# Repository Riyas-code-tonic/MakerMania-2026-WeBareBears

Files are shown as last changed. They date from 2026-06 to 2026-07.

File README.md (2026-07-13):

# MakerMania-2026-WeBareBears 
> Location: MBF Tinkerers' Lab 007
>
> Team Size: 3–5 Students
>
> Goal: Identify a real-world problem and develop an innovative, patentable, and implementable solution.

---

# 1. Team Identity

## 1.1 Team Name : We Bare Bears
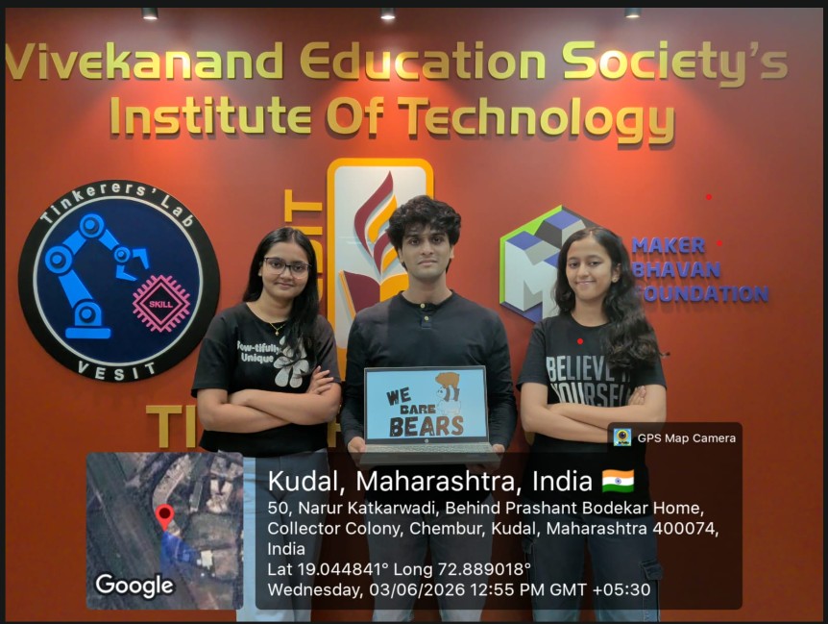
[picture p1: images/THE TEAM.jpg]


---

## 1.2 Team Members

| Name | Role | YEAR | BRANCH |
| ---- | ---- | ---- | ---- |
| Riya Pailwan | DSP & Bluetooth pairing | SE |  ETCS |
| Ankita Karmakar |  Design & Prototype | FE |  EXTC |
| Arsalan Lunje | DSP & Bluetooth pairing |  SE |  AURO |

---

# 2. Problem Discovery

## 2.1 Observation Area

Where did you conduct your observations?

Observations were conducted while travelling as a pillion passenger on a motorcycle in real urban road conditions, directly experiencing the communication difficulties caused by wind noise, engine noise, and surrounding traffic

---

## 2.2 AEIOU Observation Sheet

### Activities

What are users doing?

Riders  turn their heads, rely on shoulder taps, wait for traffic stops, or even pull over to communicate, creating inconvenience and potential safety risks.

### Environment

What conditions affect them?

Communication between riders and pillions is heavily affected by wind, engine, and traffic noise, especially at high speeds where normal conversation becomes difficult. Helmet design, rider-pillion positioning, road vibrations, weather, and high temperatures further reduce speech clarity and make effective communication challenging.

### Interactions
Who or what are they interacting with?

The rider’s attention is focused on operating the motorcycle, making communication difficult and secondary. The pillion usually communicates by shouting or tapping the rider’s shoulder, but communication is one-sided and often hindered by surrounding noise. Existing solutions like phone earbuds do not effectively address rider–pillion communication.

### Objects

What tools or products are used?

At present, most rider–pillion pairs rely on shouting or hand gestures to communicate, as there are no widely used dedicated communication tools. While premium Bluetooth intercom systems exist, they are expensive and require both users to wear compatible helmet-mounted devices. Mobile phones and earbuds are mainly used for music or navigation and do not effectively solve rider–pillion communication.

### Users

Who are the primary users?

The primary users are motorcycle riders who frequently travel with a pillion, including daily commuters, couples, families, students, and touring enthusiasts. These riders often face communication difficulties due to road and wind noise, making a simple and affordable communication solution highly valuable. The rider is the primary purchaser, while the pillion directly benefits from improved communication. By offering an easy-to-use system that does not require both users to wear specialized helmets, the solution targets a broad market and provides a practical, cost-effective alternative to expensive premium intercom systems.

---

## 2.3 Observation Log

| Observation | Evidence | Pain Point |
| --- | --- | --- |
| Rider and pillion struggle to communicate while riding. | I personally faced this issue as a pillion rider when I could not clearly hear what the rider was saying during the journey. | Miscommunication and inability to have clear conversations during the ride. |
| Riders often use unsafe or inconvenient methods to communicate. | Riders turn their heads, shout, or rely on shoulder taps and hand gestures. | Reduced riding safety and distraction from the road. |
| Existing communication systems are expensive or impractical. | Premium Bluetooth intercoms require both users to wear compatible helmet devices and can be costly. | Most everyday riders do not have access to an affordable communication solution. |

---

# 3. User Research

## 3.1 Interview Summary

Number of users interviewed: ___3___

## 3.2 Key Quotes

1. "The wind and engine noise make it difficult to hear what the other person is saying while riding."

2. "I often have to repeat myself several times before my message is understood."

3. "I sometimes need to turn back while riding just to communicate with the pillion passenger."

---

## 3.3 User Persona

## *Persona 1*

**Name:** Ashish Waghmare

**Age:** 20

**Occupation:** Student

**Goals:**
Stay connected with the pillion passenger without interrupting the journey.

**Frustrations:**
Having to repeatedly turn back to communicate with the pillion passenger.

**Needs:**
A hands-free communication solution for rider–pillion interaction.

## *Persona 2*

**Name:** Aarush Srivastava

**Age:** 20

**Occupation:** Student 

**Goals:**
To ensure safe riding while also communicating efficientlty

**Frustrations:**
When trying to communicate something specific, riders often have to shout
and repeat themselves multiple times before the pillion can understand the message 

**Needs:** 
Clear and reliable voice transmission while commuting.

## *Persona 3*

**Name:** Ekansh Bansode

**Age:** 19

**Occupation:** Student

**Goals:**
Stay focused on the road while riding.

**Frustrations:**
Pillion passengers needing to lean forward to be heard.

**Needs:**
Comfortable inside the helmet and proper comunication without interference

---

# 4. Problem Framing

## Problem Statement

A motorcycle rider and pillion passenger need a way to communicate clearly during travel because road, wind, and engine noise make verbal communication difficult and unsafe.

---

## How Might We Questions

1. How might we enable clear communication between a motorcycle rider and pillion without requiring both to wear specialized helmets?

2. How might we improve communication without requiring riders to shout or repeat themselves?

3. How might we allow riders to communicate hands-free without distracting them from riding?

---

## Opportunity Ranking

| Criteria | Score (/10) |
| --- | --- |
| Severity | 8 |
| Frequency | 8 |
| Feasibility | 7 |
| Novelty | 7 |
| Market Potential | 8 |
| **Total** | **38 / 50** |

---

# 5. Solution Ideation

| Idea | Advantages | Challenges |
| --- | --- | --- |
| **Helmet Communication System** – Enables clear rider-to-pillion communication wirelessly. | Improves communication, affordable, enhances riding convenience. | Wind noise, Bluetooth integration, and battery management. |
| **Underground Pipe Leak Detection** – Detects hidden water leaks using acoustic sensors. | Early leak detection, saves water, reduces repair costs. | Noise filtering and underground deployment complexity. |
| **Smart Lost Device Finder** – Locates misplaced remotes, earbuds, and other wireless devices. | Saves time, easy to use, reduces frustration. | Limited range and dependence on tracking hardware. |

---

## Selected Concept : Helmet Communication System

Why was this concept chosen?

We chose the **Helmet Communication System** because it addresses a problem we have personally experienced. As a pillion rider, I often found it difficult to hear what the rider was saying due to wind, traffic, and engine noise, making communication frustrating and ineffective. We also observed that many other riders and pillions face the same issue but usually accept it as a normal part of riding rather than seeking a solution. Although communication systems already exist, they typically require **both the rider and the pillion to wear compatible helmet-mounted devices**, making them expensive and impractical for everyday use. Our concept aims to provide a simpler, more affordable solution that enables clear communication without requiring both users to use specialized helmets.

---

# 6. System Design

## High-Level Description

The proposed system is a low-cost wireless rider–pillion communication solution designed for motorcycles. The rider's or pillion passenger's voice is captured using an INMP441 MEMS microphone, which converts sound into digital audio data and transmits it to the ESP32 through the I²S protocol.

The ESP32 performs audio processing functions such as noise filtering, gain control, voice enhancement, and audio formatting to improve speech clarity in noisy riding environments. The processed audio is then converted into analog audio output using the ESP32's built-in DAC and transmitted through ESP's built in bluetooth module.

The ESP wirelessly streams the audio via Bluetooth to a paired Bluetooth earbud or earpiece, allowing clear communication between the rider and pillion passenger.

The system is powered by a 3.7V Li-Po battery charged through a TP4056 charging module. A 7Semi 5V to 3.3V 1A LDO regulator provides a stable 3.3V supply to the ESP32 and INMP441 microphone, while the RS2597 Bluetooth module is powered directly from the Li-Po battery.

---

## Block Diagram

Insert diagram here.
```text

                        ┌───────────────────┐    ┌───────────────────┐    ┌───────────────────┐       ┌───────────────────┐    ┌───────────────────┐
                        │   Voice Input     │───►│  Voice Capture    │───►│ Audio Processing  │─────► │ Audio Received    │───►│   Clear Audio     │
                        │                   │    │                   │    │ & Noise Reduction │       │         by        │    │      Heard        │
                        │ Rider / Pillion   │    │ INMP441 MEMS Mic  │    │      ESP32        │       │ Bluetooth Earbud  │    │     by User       │
                        │      Speaks       │    │                   │    │                   │       │   / Earpiece      │    │                   │
                        └───────────────────┘    └─────────▲─────────┘    └─────────▲─────────┘       └───────────────────┘    └───────────────────┘
                                                                                    │                                               
                                                                                    │                                              
                                                                           3.3 V Stable Power                    
                                                                                    │                           
                                                                                    │                             
                        ┌───────────────────┐    ┌───────────────────┐    ┌───────────────────┐                 
                        │  TP4056 Module    │───►│   Li-Po Battery   │───►│ 7Semi 5V to 3.3V  │                 
                        │ Charging &        │    │ 3.0V - 4.2V       │    │      1A LDO       │                 
                        │ Protection        │    │ (Nom. 3.7V)       │    │   3.3V Output     │                  
                        └───────────────────┘    └───────────────────┘    └───────────────────┘                
                                                                                                                          
```
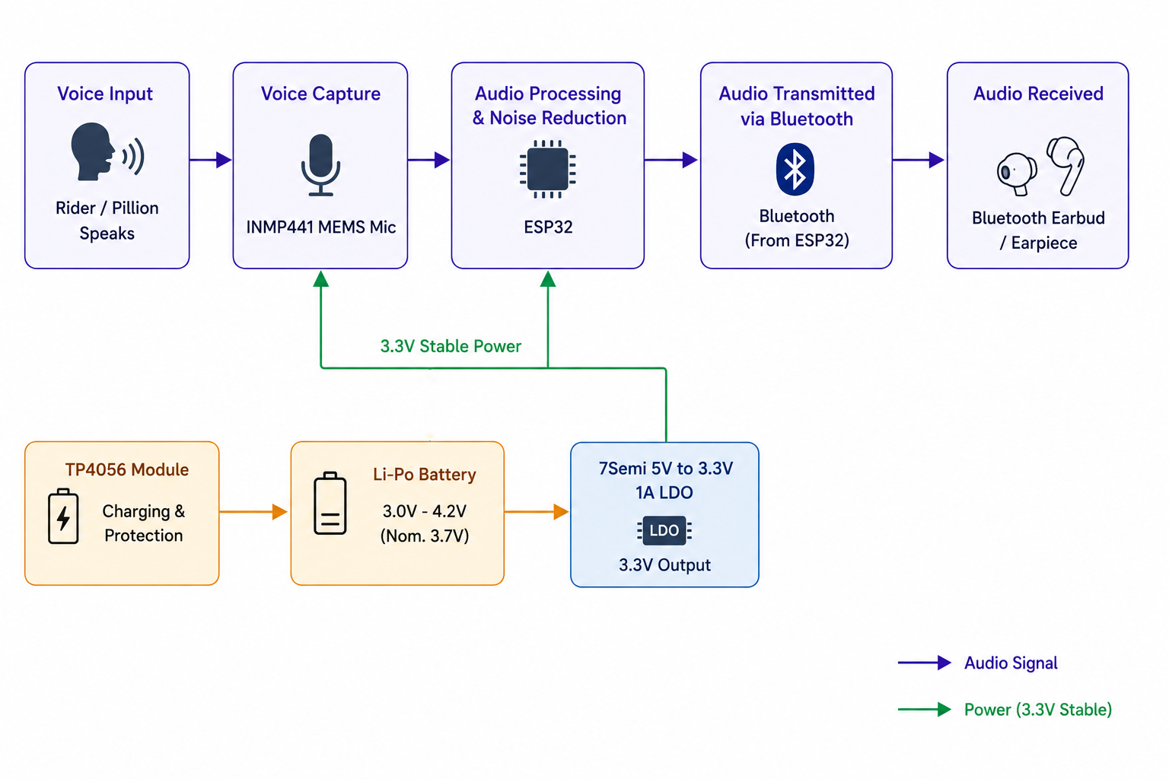
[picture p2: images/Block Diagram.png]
Block Diagram

## System Architecture

                    ┌─────────────┐
                    │   TP4056    │
                    │  Charging   │
                    │  Module     │
                    └──────┬──────┘
                           │
                           ▼
                    ┌─────────────┐
                    │ Li-Po       │
                    │ Battery     │
                    │ 3.7V        │
                    └───┬─────────┘
                        │     
                        │     
                        │     
                        │ 
                        │    ┌─────────────────┐
                        │    │ Bluetooth Earbud│
                        │    └────────▲────────┘
                        │             │
                        │             │
                        ▼             │─ DAC─► Analog Audio 
                 ┌─────────────┐      │─ Noise Filtering
                 │ 7Semi 5V to │      │─ Gain Control
                 │ 3.3V 1A LDO │      │─ Voice Enhancement
                 └──────┬──────┘      │─ Audio Formatting
                        │             │
                        ▼             │
                 ┌─────────────┐  I²S │
                 │   ESP32     │──────│
                 └──────▲──────┘
                        │ 
                        │
                 ┌──────│──────┐
                 │  INMP441    │
                 │ MEMS Mic    │
                 └─────────────┘
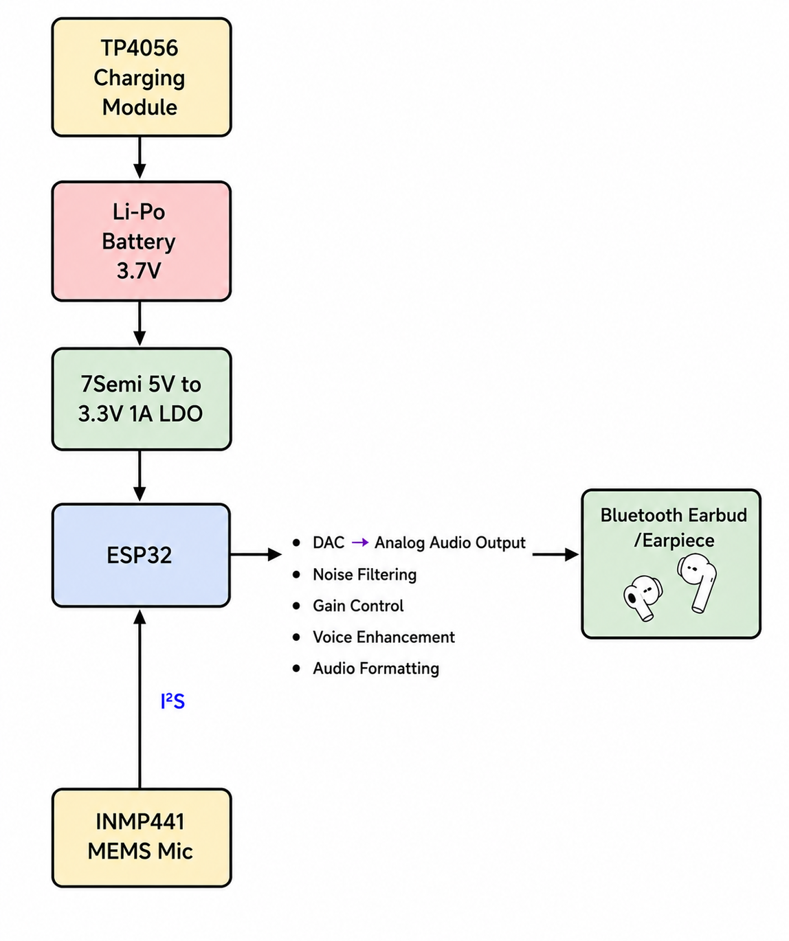
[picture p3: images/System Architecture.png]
System Architecture
               
## Inputs

List sensors, user inputs, data sources.
|INPUT|SOURCE|
|---|---|
|Rider Voice|INMP441 MEMS Microphone|
|Power Supply|3.7V Li-Po Battery|
---

## Outputs

List displays, actuators, software outputs.
|OUTPUT|DEVICE|
|---|---|
|Processed Audio Communication|Bluetooth Earbud|
---

# 7. Technical Planning

## Electronics

|Sr.No. | Component | Purpose | Links|
|--| ---- | --- | --- |
|1.| INMP441 MEMS Microphone |Captures the rider's or pillion's voice and converts it into digital audio data using the I2S interface. |https://robu.in/product/inmp441-mems-high-precision-omnidirectional-microphone-module-i2s/|
|2.| ESP32 Dev Kit V1 |Acts as the main controller, processes audio data, performs noise filtering, and manages wireless communication. |https://www.amazon.in/Generic-ESP32-Dev-Kit-V1/dp/B0H26254W7|
|3.| TP4056 Charging Module |Charges and protects the lithium-ion battery from overcharging and over-discharging. |https://robu.in/product/tp4056-1a-li-ion-lithium-battery-charging-module-with-current-protection-type-c/|
|4.| 3.7V Li-Po Battery |Provides portable power to the entire communication system. |https://www.amazon.in/Bhajanlal-Greenery-Rechargeable-Lithium-Batteries/dp/B0CYQ6H8FW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|
|5.| Bluetooth Earbud |Receives and plays the transmitted audio to the user. ||
|6.| 7Semi 5V to 3.3V 1A LDO Low Dropout Regulator |Provides a stable 3.3V supply to the ESP32, INMP441, and other low-voltage components. |https://evelta.com/7semi-5v-to-3-3v-1a-ldo-low-dropout-regulator-breakout-with-enable/|

Component List : [📄 Component List](docs/Component%20List.docx)
---

## Software

| Tool | Purpose |
| ---- | --- |
|  Arduino IDE | processesing audio data, dsp, performs noise filtering, and manages wireless communication. |

---

## Mechanical / CAD
[Prototype 2 - RideConnect STL](cad/Prototype2%20-%20RideConnect.stl)
Describe fabricated components.

---

# 8. Prototype Development

## Version 1

Description: The first prototype focused on validating the communication concept. Individual components such as the ESP32, MEMS microphone, Bluetooth module, and power supply were tested independently to ensure proper functionality.

Lessons Learned:
- Verified the functionality of individual hardware components before system integration.
- Identified the importance of testing each module independently to simplify debugging.
- Gained an understanding of power requirements, hardware compatibility, and communication interfaces.

---

## Version 2

Description: The immediate prototype involved integrating all the selected hardware components into a single compact embedded system to validate the concept. An ESP32 microcontroller was interfaced with the INMP441 MEMS microphone using the I²S protocol to capture digital audio, while a Bluetooth audio module was used to transmit the processed voice wirelessly to a Bluetooth earbud.
Initial firmware was developed to perform basic audio acquisition, signal processing, and wireless transmission. Testing of the prototype helped identify issues such as wind noise interference, audio latency, power stability, and Bluetooth connectivity. Based on these observations, the system was further refined by optimizing the audio processing pipeline, improving power management, and enhancing the overall reliability of the communication system.

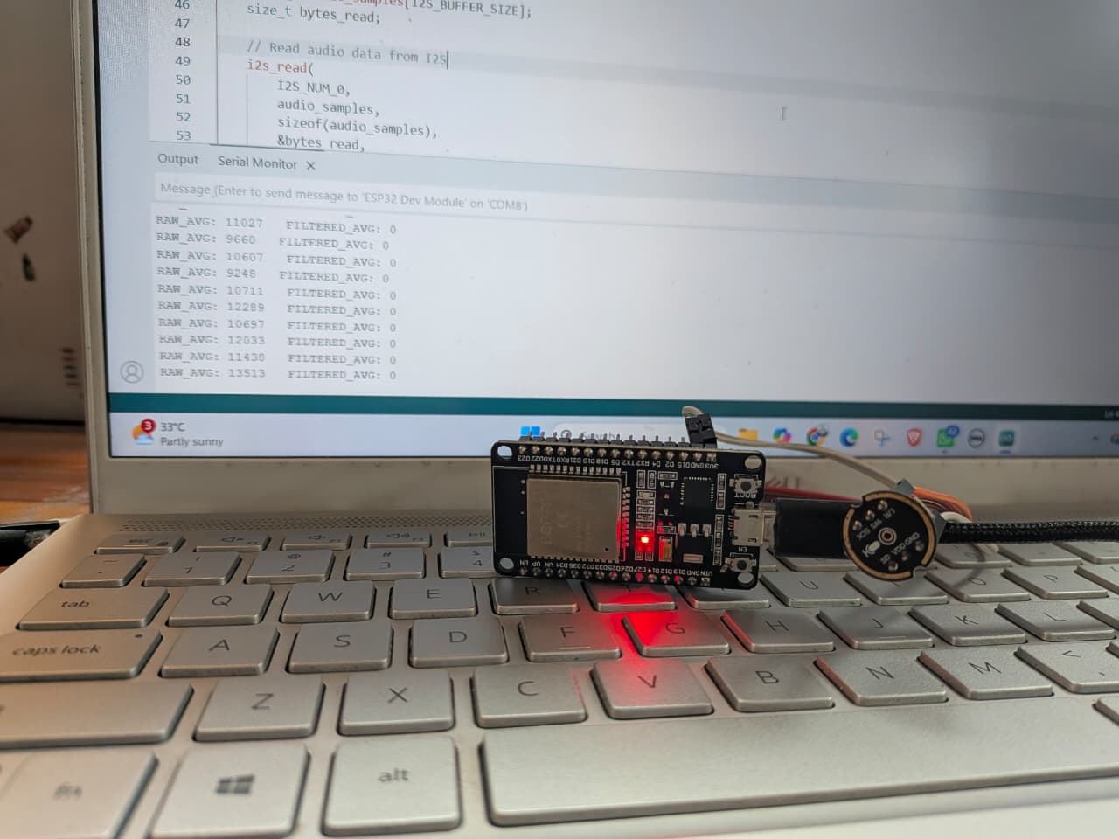
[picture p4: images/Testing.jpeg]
Testing


Lessons Learned:
- Integrating all hardware components introduced challenges such as speech clipping, audio latency, Bluetooth pairing issues, and wind noise interference.
- DSP algorithms required extensive tuning to achieve a balance between noise reduction, amplification, and speech clarity.
- Stable Bluetooth connectivity and efficient power management were essential for reliable real-time communication.
- Testing in different environments helped identify practical limitations and guided further optimization of the system.

---

## Final Prototype

Description: The final prototype consists of an ESP32-based communication unit powered by a rechargeable Li-Po battery. An INMP441 MEMS microphone captures the rider's or pillion's voice, while the ESP32 processes the audio using noise reduction and gain control algorithms. The processed audio is transmitted wirelessly to a Bluetooth earbud, enabling clear communication without requiring specialized helmet-mounted intercoms. The design is lightweight, portable, rechargeable, and cost-effective, making it suitable for daily commuters as well as long-distance riders.

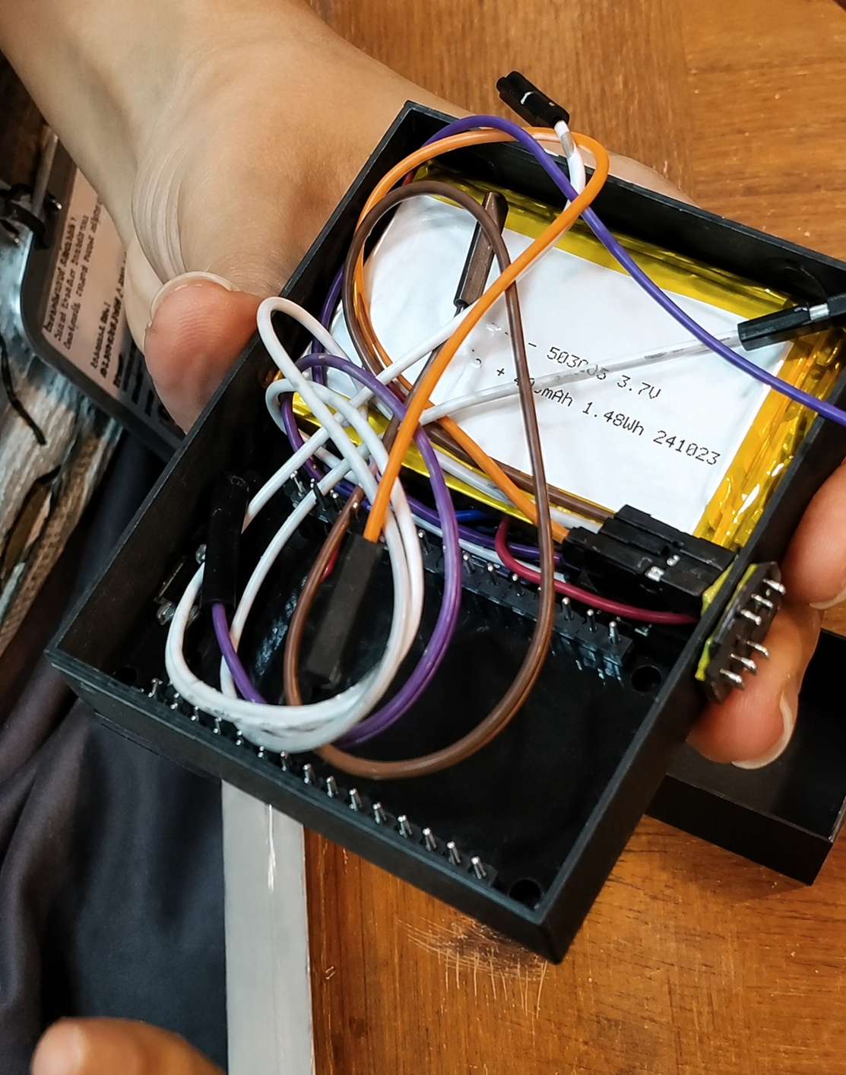
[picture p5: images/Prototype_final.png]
Final Prototype

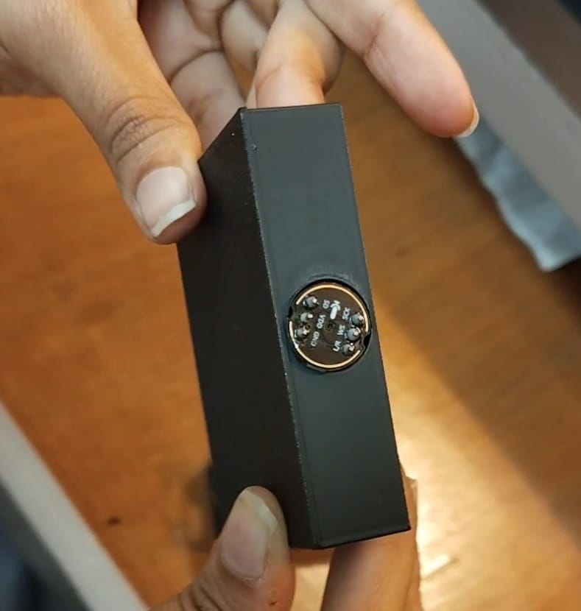
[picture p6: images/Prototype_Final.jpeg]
Final Prototype

---

# 9. Testing & Validation

## Testing Plan

| Test | Success Criteria |
|---|---|
| Audio Capture | MEMS microphone accurately captures speech with minimal distortion. |
| Audio Transmission | Speech is transmitted wirelessly to the Bluetooth earbuds without interruptions. |
| DSP Performance | Noise reduction and gain control improve speech clarity while preserving voice quality. |
| Latency Test | End-to-end audio delay remains low enough for comfortable real-time communication. |

---

## User Feedback

| User | Feedback | Action Taken |
| ---- | --- | --- |
| | | |

---

# 10. Innovation Assessment

## Existing Solutions

List competing products.

---

## What Makes This Different?

---

## Innovation Score

| Parameter | Score |
| --- | ----- |
| Novelty | |
| Technical Depth | |
| Feasibility | |
| Impact | |
| Scalability | |

---

# 11. Intellectual Property

## Prior Art Search

Patents / Products Found:

---

## Novel Features

1.

2.

3.

---

## Provisional Patent Draft

### Title

### Abstract

### Problem

### Solution

### Claims

---

# 12. Business & Deployment

## Target Users

---

## Estimated Cost

---

## Market Opportunity

---

## Sustainability Considerations

---

# 13. Final Demonstration

## Prototype Images

Insert photos.

---

## Demonstration Video Link

---

## GitHub Repository

---

## Presentation Link

---

# 14. Reflection

## What Worked Well?

---

## What Failed?

---

## Key Learnings

---

## Next Steps

* Patent Filing
* Startup Exploration
* Product Development
* Research Publication
* Competition Submission

---

# 15. Final Deliverables Checklist

* Problem Discovery Complete
* User Interviews Complete
* Persona Created
* Problem Statement Finalized
* System Design Complete
* Prototype Demonstrated
* Testing Completed
* Patent Draft Prepared
* Presentation Submitted
* GitHub Repository Updated

---

# MAKERMANIA FINAL PITCH

Each team will present:

1. Problem
2. User Research
3. Insights
4. Solution
5. Prototype Demo
6. Innovation & Patentability
7. Future Roadmap

Presentation Time: 5 Minutes

Q&A: 3 Minutes

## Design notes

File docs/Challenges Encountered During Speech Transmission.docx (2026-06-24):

Challenges Encountered During Speech Transmission

While developing the speech communication system using a MEMS microphone, ESP32, and Bluetooth earbuds, the following issues were identified:

1. Initial Speech Clipping The first word or a few initial syllables of a spoken sentence are occasionally omitted during transmission.
2. Inter-Sentence Audio Loss When transitioning from one sentence to the next, portions of speech may be dropped, resulting in incomplete audio transmission.
3. End-of-Sentence Clipping The last few letters or syllables of a sentence are sometimes not transmitted successfully.
4. Bluetooth Pairing Security The earbuds should only connect to the intended communication module and must be protected from unauthorized pairing attempts while in pairing mode.
5. Connection Stability Once connected, the earbuds should maintain the Bluetooth connection and should only disconnect when placed back into their charging case.
6. Wind Noise Interference Wind noise significantly affects microphone performance and reduces speech intelligibility in outdoor environments.
7. Speech Latency Noticeable delay exists between speech capture and audio playback, impacting real-time communication.

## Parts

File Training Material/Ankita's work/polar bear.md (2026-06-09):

## 2 June 2026 
-> 3D modelling in Fusion360, learning modelling of a bottle

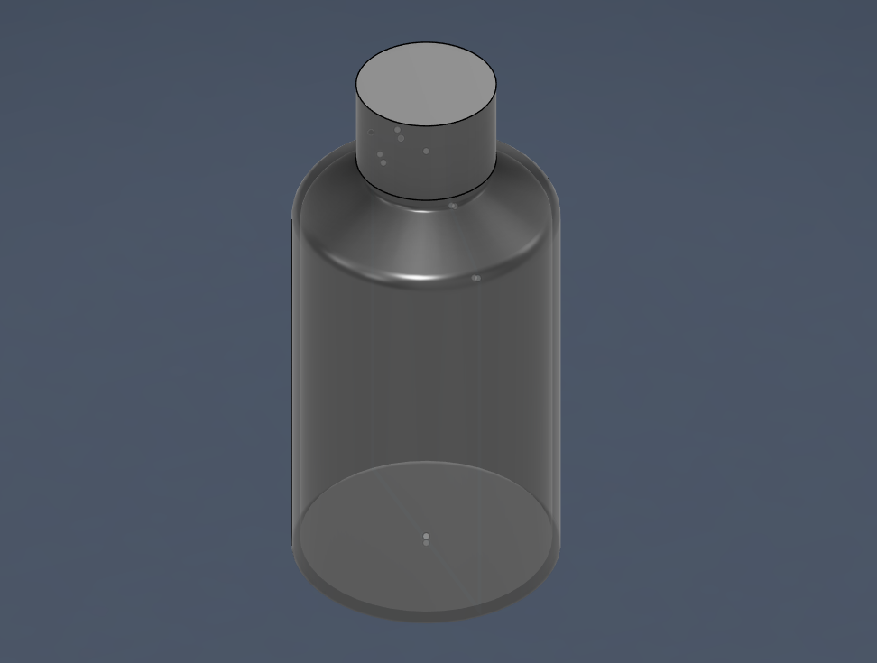
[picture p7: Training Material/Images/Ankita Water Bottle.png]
Ankita Water Bottle


-> Google Meet with an Alumnus, Prithvi Shetty. Spoke about his project 'TARA' and the critical roadmap to building and selling a product.

## 3 June 2026 
-> 3D models of stuffing box and keychain

-> Laser Cutting, learned to laser cut designs as keychains

-> Brainstorming useless product ideas

## 4 June 2026 
-> Laser cut MBFTL IDs

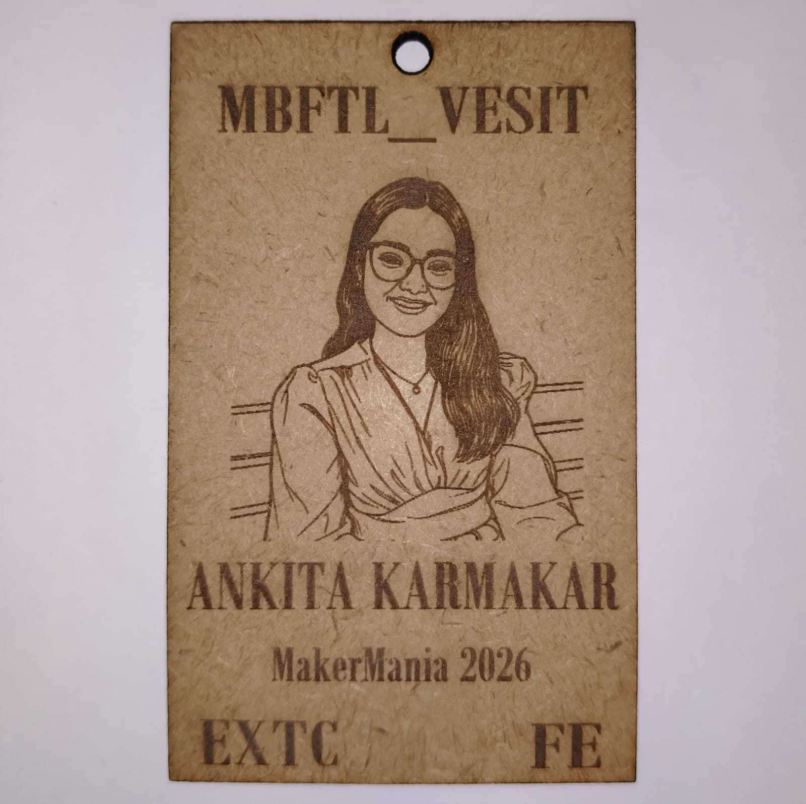
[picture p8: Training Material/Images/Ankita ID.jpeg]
Ankita ID


-> 3D modelling final selected useless product

-> Learned 3D printing

-> 3D printed our 'USELESS' product

## 5 June 2026 ->
Recorded the pitch video for our *USELESS* product.

## 6 June 2026

- Edited the pitch video for our *USELESS* product.
- Uploaded the final video.
### Video
[Watch the Final Video](https://youtu.be/IZlCxVAjYFc)

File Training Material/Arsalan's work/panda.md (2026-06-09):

## 2 June 2026 
-> 3D modelling in Fusion360, learning modelling of a bottle

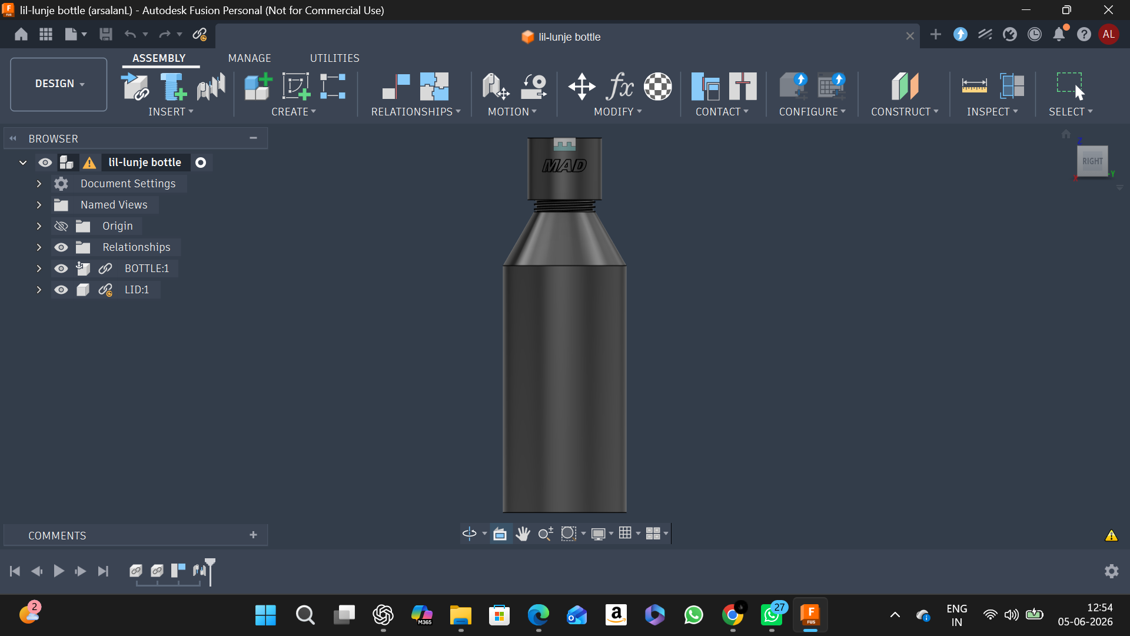
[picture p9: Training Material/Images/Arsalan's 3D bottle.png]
Arsalan's 3D Bottle


-> Google Meet with an Alumnus, Prithvi Shetty. Spoke about his project 'TARA' and the critical roadmap to building and selling a product.

## 3 June 2026 
-> 3D models of stuffing box and keychain

-> Laser Cutting, learned to laser cut designs as keychains

-> Brainstorming useless product ideas

## 4 June 2026 
-> Took a leave

## 5 June 2026 
-> Laser cut MBFTL IDs

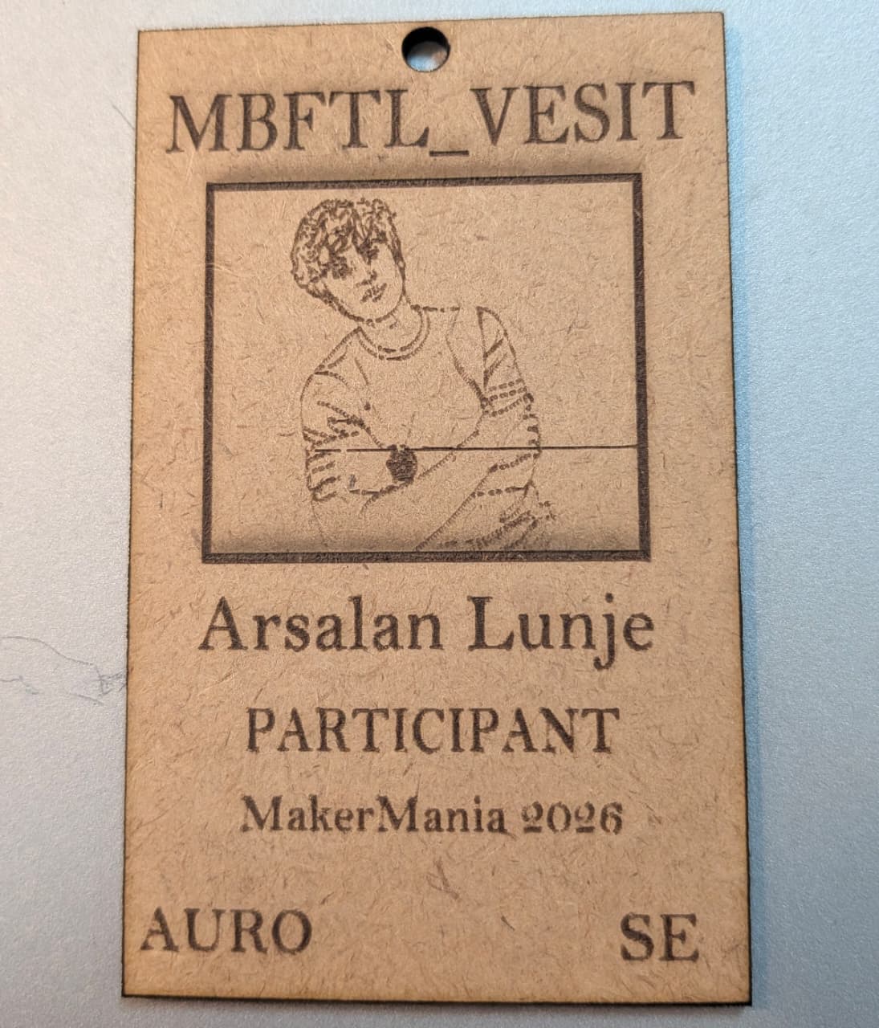
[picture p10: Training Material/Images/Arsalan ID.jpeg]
Arsalan ID


## 6 June 2026

- Edited the pitch video for our *USELESS* product.
- Uploaded the final video.
### Video
[Watch the Final Video](https://youtu.be/IZlCxVAjYFc)

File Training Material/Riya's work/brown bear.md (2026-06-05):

# Riya's MakerMania Work Log

## 2 June 2026

- Learned 3D modelling in Fusion 360 by creating a bottle model.

### Photo
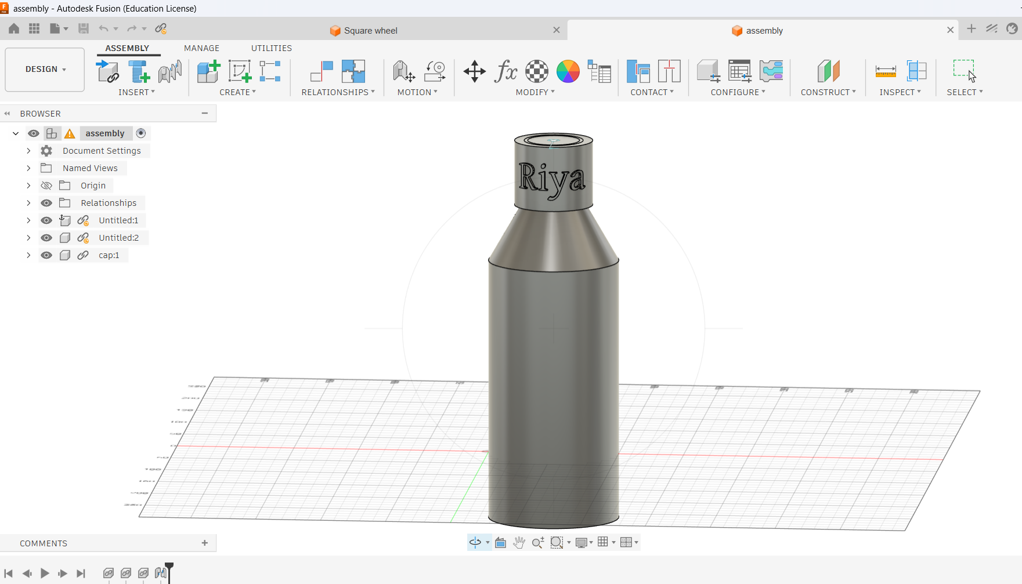
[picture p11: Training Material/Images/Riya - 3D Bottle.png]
Bottle Model


- Attended a Google Meet with alumnus **Prithvi Shetty**.
  - Discussed his project **TARA**.
  - Learned about the roadmap for building and selling a product.

---

## 3 June 2026

- Created 3D models of:
  - Stuffing Box
  - Keychain

- Learned laser cutting and created keychain designs.
- Brainstormed ideas for a useless product.

---

## 4 June 2026

- Laser-cut MBFTL ID cards.

### Photo
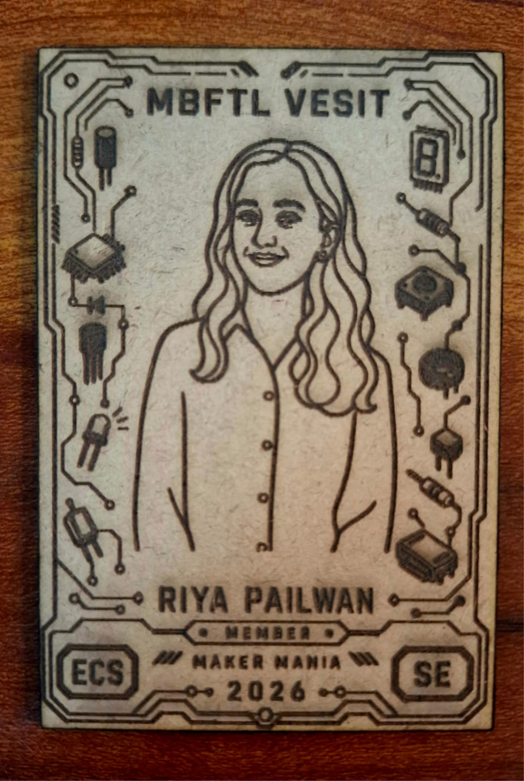
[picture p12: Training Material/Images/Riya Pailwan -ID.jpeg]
MBFTL ID


- Finalized the design of our useless product.
- Learned the basics of 3D printing.
- Successfully 3D printed our **USELESS** product.

### Photo
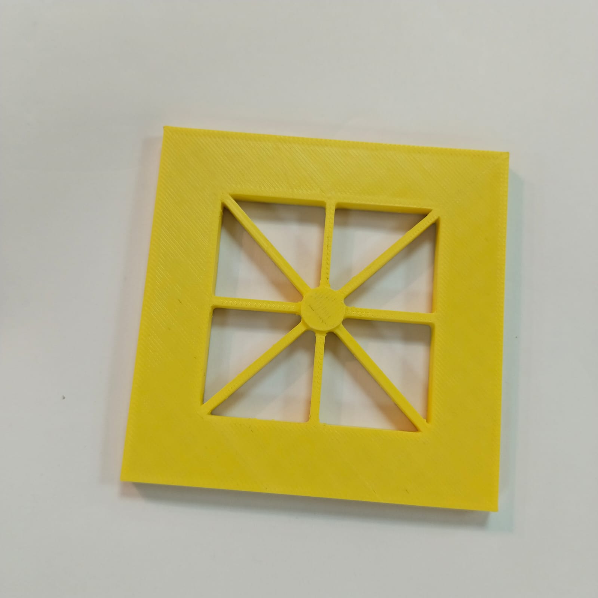
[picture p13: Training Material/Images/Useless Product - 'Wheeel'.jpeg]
Useless Product


---

## 5 June 2026

- To be updated.

---

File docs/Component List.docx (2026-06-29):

Components | Links
MEMS Microphone (INMP441) | Buy INMP441 MEMS High Precision Omnidirectional Microphone Module I2S | Robu.in (https://robu.in/product/inmp441-mems-high-precision-omnidirectional-microphone-module-i2s/)
ESP32 (Bluetooth Active) | ESP32 Dev Kit V1 : Amazon.in: Industrial & Scientific (https://www.amazon.in/Generic-ESP32-Dev-Kit-V1/dp/B0H26254W7)
7Semi 5V to 3.3V 1A LDO Low Dropout Regulator | Buy 7Semi 5V to 3.3V 1A LDO Low Dropout Regulator Breakout with ENABLE | Evelta (https://evelta.com/7semi-5v-to-3-3v-1a-ldo-low-dropout-regulator-breakout-with-enable/)
Charging Module (TP4056) | Buy TP4056 1A Li-ion Charging Module With Current Protection | Robu.in (https://robu.in/product/tp4056-1a-li-ion-lithium-battery-charging-module-with-current-protection-type-c/)
LiPo Battery | Lipo Rechargeable Battery 3.7V 300mAh (https://www.amazon.in/Bhajanlal-Greenery-Rechargeable-Lithium-Batteries/dp/B0CYQ6H8FW)

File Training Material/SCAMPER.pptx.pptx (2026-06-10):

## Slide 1

SCAMPER

Wireless Controller Tracker

Problem: Misplaced remote or controller? Your device should be able to locate itself

S

C

A

M

P

E

R

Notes: Welcome! Today I'm applying SCAMPER to solve a simple but annoying problem: losing your TV remote or game controller. Let's go.
1

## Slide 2

S

Substitute

S

Replace manual searching with a smartphone-based locating system that allows users to instantly find misplaced wireless devices.

SCAMPER · Find My Controller

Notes: Speak for 4 seconds: Read letter, word, and idea.
2

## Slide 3

C

Combine

C

Combine wireless devices with smart home assistants, allowing users to locate devices through voice commands.

SCAMPER · Find My Controller

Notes: Speak for 4 seconds: Read letter, word, and idea.
3

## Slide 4

A

Adapt

A

Adapt the functionality of Apple's Find My and AirTag ecosystem to create a tracking network for wireless controllers.

SCAMPER · Find My Controller

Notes: Speak for 4 seconds: Read letter, word, and idea.
4

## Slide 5

M

Modify

M

Modify device firmware so the home hub, that is, the TV or console can broadcast a "ping" signal the controller responds to

SCAMPER · Find My Controller

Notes: Speak for 4 seconds: Read letter, word, and idea.
5

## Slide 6

P

Put to other uses

P

Use the controller's wireless communication module for real-time location tracking and it’s vibration motor to provide haptic feedback, making it easier to locate when hidden under cushions or furniture.

SCAMPER · Find My Controller

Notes: Speak for 4 seconds: Read letter, word, and idea.
6

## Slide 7

E

Eliminate

E

Eliminate time-consuming manual searches by providing a dedicated “Find Device” button on the connected TV, console, or smartphone app.

SCAMPER · Find My Controller

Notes: Speak for 4 seconds: Read letter, word, and idea.
7

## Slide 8

R

Reverse / Rearrange

R

Instead of users searching for controllers, enable controllers to automatically notify users when they are left in unusual locations.

SCAMPER · Find My Controller

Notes: Speak for 4 seconds: Read letter, word, and idea.
8

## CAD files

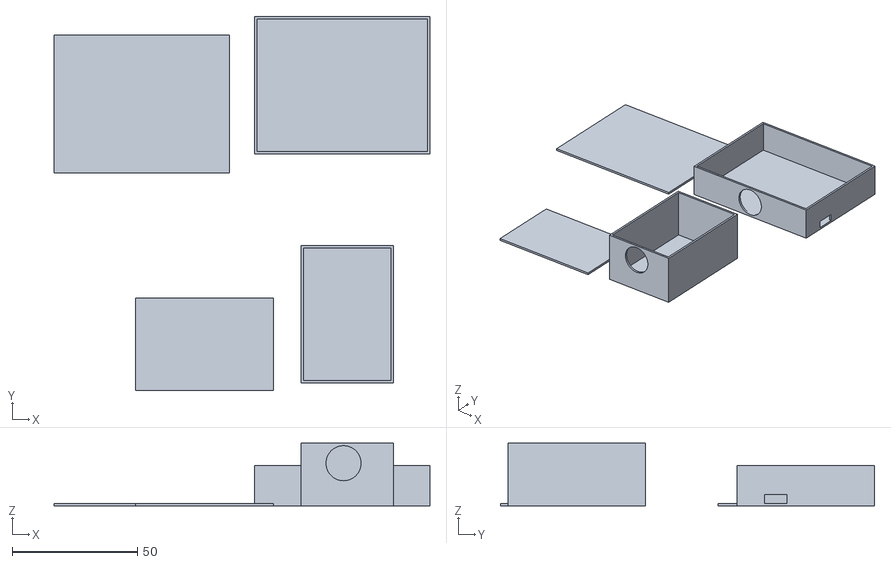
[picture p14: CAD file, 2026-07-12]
cad/Prototype2 - RideConnect.stl
150.0 x 149.4 x 25.0

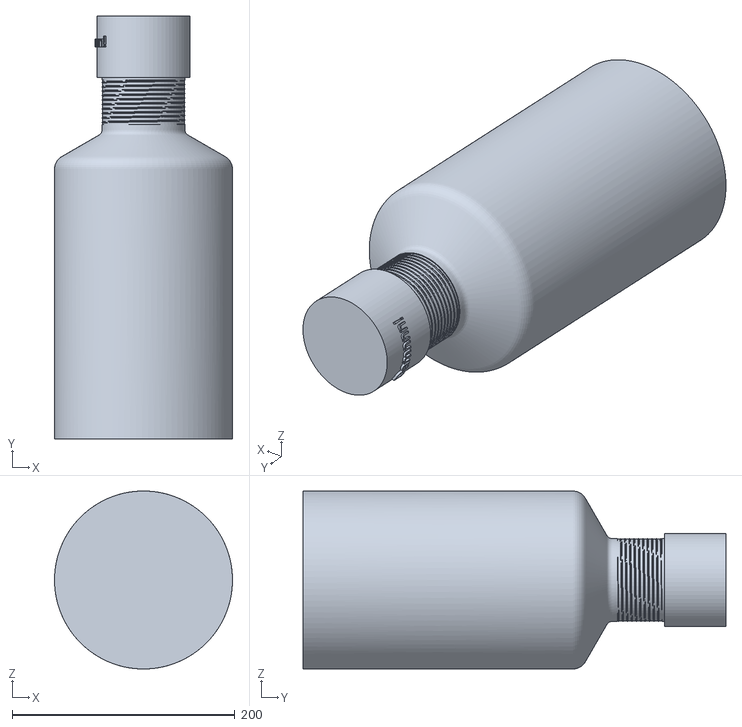
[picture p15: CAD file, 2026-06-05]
Training Material/CAD/Ankita Water Bottle.stl
160.0 x 380.0 x 160.0

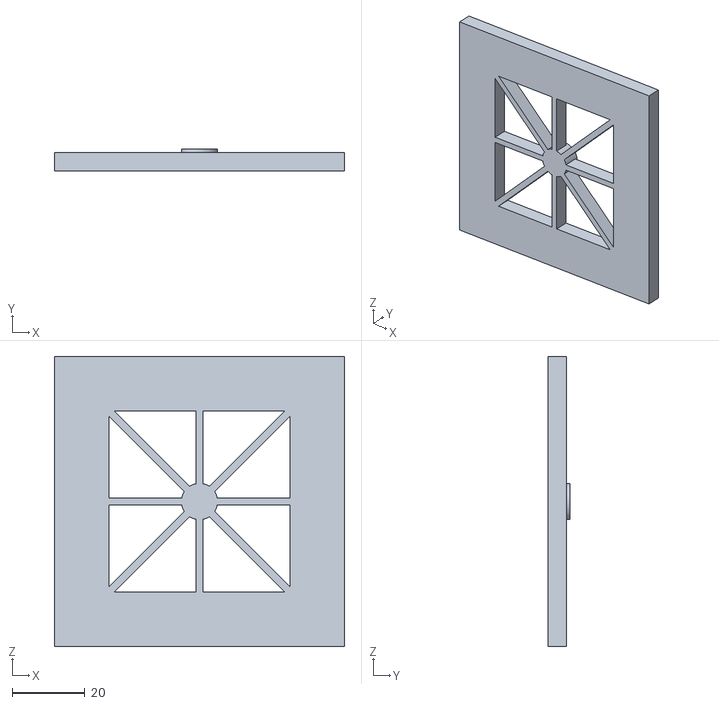
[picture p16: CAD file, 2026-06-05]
Training Material/Useless product/Square_wheel.stl
80.0 x 6.00 x 80.0

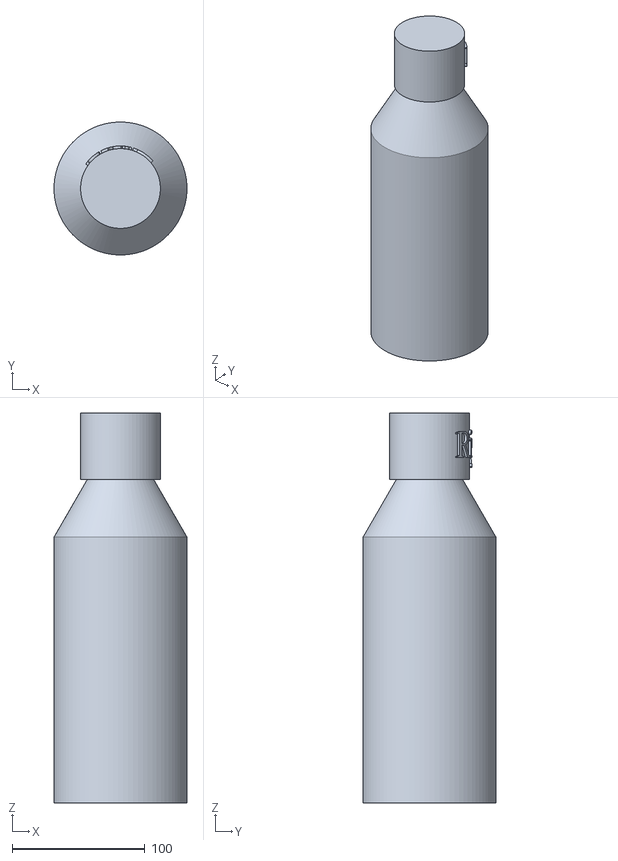
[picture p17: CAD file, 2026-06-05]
Training Material/CAD/Riya-3D Bottle.stl
100.0 x 99.9 x 293.3

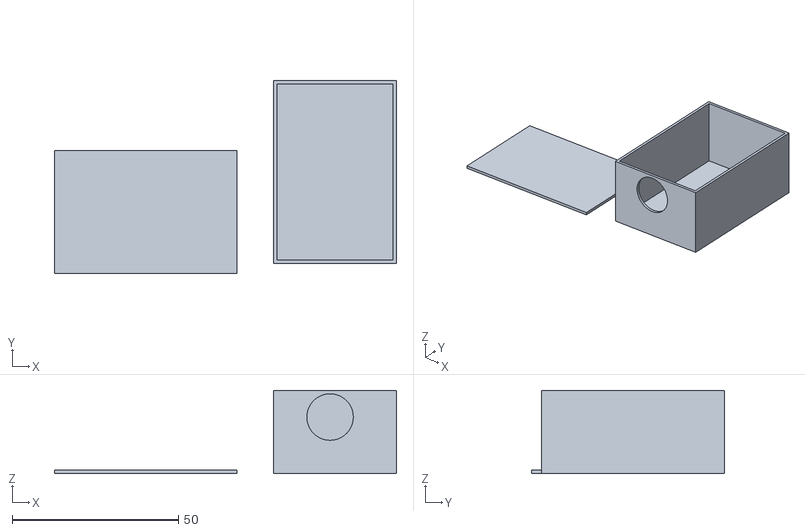
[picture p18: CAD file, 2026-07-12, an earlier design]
cad/Prototype1 - RideConnect.stl
103.0 x 58.0 x 25.0

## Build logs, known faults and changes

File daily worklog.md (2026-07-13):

 <h2 align="center"> Daily Worklog (After Training Week)</h2>
 
 ## 8 June 2026

- Discussed the *SCAMPER Framework* for the ideation phase.
- Applied the framework to a real pain point faced by our team.
- Developed a solution around the problem statement:

  > Develop a smart system that enables wireless controllers to be easily located and proactively alert users when they are misplaced.

- Prepared a presentation explaining the problem statement and our proposed solution.
  
---

## 9 June 2026

- Thought of and researched everyday problems faced by people in daily life to identify potential areas for innovation and problem-solving.
- Started learning the basics of the **ESP32** and **IO Shield**.
- Learned to blink LEDs using the ESP32.
- Created different LED patterns and sequences.
- Explored the use of a buzzer.

---

## 10 June 2026

- Presented a problem statement developed using the **SCAMPER Framework**.
- Explored and discussed multiple potential problem statements and their feasibility.
- Received valuable insights and feedback from professors regarding our logic, approach, and thought process.
- Refined our understanding of problem identification and solution development through discussions and evaluations.

---

## 11 June 2026

- Narrowed down and finalized the problem statement for further development.
- The "Acoustic Fingerprint" Subsurface Leak Detector (IoT & Infrastructure)
- Conducted additional research on the selected problem statement.
- Gained deeper insights into the problem domain and its real-world significance.
- Improved clarity regarding the scope, challenges, and potential solution approaches.
- Built an **8-bit binary counter** using LEDs and the ESP32 module.
- Learned how binary counting can be represented and visualized using LEDs.

---

## 12 June 2026

- Learned the basics of KiCad
- Narrowed down our problem statement and chose to work on a "Tap Leak Detector"
- Further conducted our research towards the above problem statement 
- Compiled a list of 50 problems for the problem sheet.

---

## 13 June 2026

- Researched the **Water Tap Leak Detection System** problem statement and explored its practical applications.
- Investigated additional problem statements to evaluate their feasibility and impact.
- Contributed new ideas and added more potential problem statements to the team's list of 50 problem statements.
- Began researching the **Helmet Pillion Communication** problem statement, focusing on existing solutions and potential areas for innovation.

---

## 15 June 2026

- Finalized the project problem statement:

  > Motorcycle riders often struggle to communicate with pillion passengers due to environmental noise during travel. Wind, engine, and traffic noise significantly reduce speech clarity, making real-time communication difficult and distracting.

- Conducted thorough research to understand the problem domain and validate the proposed solution.
- Analyzed the advantages, limitations, and challenges associated with the project.
- Explored various hardware components and technologies suitable for implementing the solution.

---

## 16 June 2026

- Evaluated different component options based on functionality, compatibility, and project requirements.
- Compared component specifications and suitability to ensure alignment with the project objectives.
- Prepared the component list for procurement and future implementation stages.
- Designed a block diagram explaining the logic

---

## 17 June 2026

- Finalized the component list required for the project.
- Reviewed component specifications and compatibility for system integration.
### MEMS Microphone
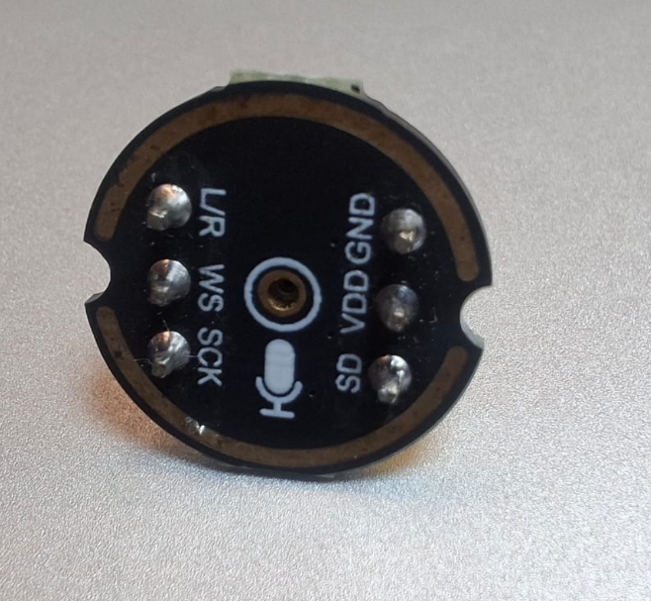
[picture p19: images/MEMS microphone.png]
MEMS microphone

---

## 18 June 2026

- Performed initial testing of the MEMS microphone.
- Verified microphone functionality and audio signal acquisition.

---

## 20 June 2026

- Captured and analyzed environmental noise samples.
- Studied sources of noise such as wind, engine, and traffic sounds.
- Explored noise filtering techniques using the ESP32 for improved voice clarity.
### Noise filtering attempts 
Testing

---

## 22 June 2026

- Analyzed and tested the speech transmission code used for audio communication between the MEMS microphone and Bluetooth earbuds. 
- Investigated the data flow through the ESP32 to identify potential sources of audio loss and latency.
- Documented observed issues and evaluated areas for further optimization and debugging.

---

## 23 June 2026

- Worked on debugging potential errors in the speech transmission system and analyzed their impact on audio quality. 
- Tested various voice filtering techniques to improve speech clarity and reduce unwanted background noise.
- Evaluated filter performance and documented observations for further optimization.
  
---

## 24 June 2026

- Conducted a detailed review and scrutiny of the speech transmission code. Analyzed the existing implementation, modified key parameters, and optimized several variables to improve overall system performance and stability.
- Completed the implementation and testing of the DSP (Digital Signal Processing) pipeline. Performance was evaluated in multiple environments, including a quiet room, a crowded indoor setting, and areas with significant traffic noise to assess noise suppression effectiveness.
- Successfully established a Bluetooth audio connection between the ESP32's built-in Bluetooth module and the target Bluetooth earbuds. Verified stable pairing and audio transmission functionality.
- Achieved end-to-end voice communication through the system. Speech captured by the MEMS microphone was processed by the ESP32, transmitted via Bluetooth, and successfully played back through the connected earbuds.

- Understood problems and dealt with them
  
> Challenges Encountered During Speech Transmission
While developing the speech communication system using a MEMS microphone, ESP32, and Bluetooth earbuds, the following issues were identified:
> 1.	Initial Speech Clipping
The first word or a few initial syllables of a spoken sentence are occasionally omitted during transmission.
> 2.	Inter-Sentence Audio Loss
When transitioning from one sentence to the next, portions of speech may be dropped, resulting in incomplete audio transmission.
> 3.	End-of-Sentence Clipping
The last few letters or syllables of a sentence are sometimes not transmitted successfully.
> 4.	Bluetooth Pairing Security
The earbuds should only connect to the intended communication module and must be protected from unauthorized pairing attempts while in pairing mode.
> 5.	Connection Stability
Once connected, the earbuds should maintain the Bluetooth connection and should only disconnect when placed back into their charging case.
> 6.	Wind Noise Interference
Wind noise significantly affects microphone performance and reduces speech intelligibility in outdoor environments.
> 7.	Speech Latency
Noticeable delay exists between speech capture and audio playback, impacting real-time communication.

---

## 25 June 2026

- Worked on resolving the issues of **Initial Speech Clipping** and **Inter-Sentence Audio Loss** in the speech transmission pipeline. Investigated the underlying causes by analyzing the audio processing flow, tuning relevant parameters, and testing multiple configurations to improve the continuity of speech transmission.
- During the debugging process, encountered an issue with **audio amplification**, where the processed audio exhibited inconsistent output levels. Began analyzing the DSP pipeline and gain settings to identify the source of the amplification problem and determine appropriate corrective measures.

---

## 27 June 2026

- Worked on resolving the End-of-Sentence Clipping issue, where the last few letters or syllables of a sentence were occasionally omitted during transmission. Analyzed the speech processing pipeline, adjusted relevant parameters, and performed repeated testing to improve complete audio delivery.
- Investigated the Bluetooth pairing mechanism to ensure that the earbuds connect only to the intended ESP32 module. Evaluated pairing behavior and explored methods to improve connection reliability while preventing unintended connections to other nearby Bluetooth devices.

---

## 29 June 2026

- Worked on improving **Bluetooth connection stability** to ensure that the earbuds maintain a persistent connection with the ESP32 during operation. Investigated reconnection behavior and explored methods to prevent unintended disconnections until the earbuds are placed back in their charging case.
- Evaluated the impact of **wind noise interference** on the MEMS microphone and analyzed its effect on speech intelligibility in outdoor environments. Tested the DSP pipeline under different conditions to identify opportunities for improving noise suppression.
- Analyzed the causes of **speech latency** in the audio transmission pipeline. Investigated the contribution of audio buffering, DSP processing, and Bluetooth transmission to reduce end-to-end delay and improve real-time communication.
- Studied **RSSI (Received Signal Strength Indicator)** and Bluetooth device discovery techniques. Explored Bluetooth scanning and discoverable device mechanisms to better understand connection management, device selection, and pairing optimization.

---

## 30 June 2026

- Encountered issues with **voice amplification**, where the output audio exhibited inconsistent gain levels and excessive amplification. Investigated the DSP gain stages and audio processing pipeline to identify the source of the problem and evaluate possible solutions.
- Identified challenges related to **noise cancellation**, as background noise suppression affected speech quality under certain conditions. Analyzed the performance of the current noise reduction algorithm and tested different configurations to improve speech clarity while minimizing distortion.

---

## 1 July 2026

- Worked on resolving **voice amplification** issues by analyzing the DSP pipeline and adjusting audio gain parameters. Tested multiple configurations to achieve consistent output levels while maintaining clear and distortion-free speech.
- Worked on **Bluetooth device scanning and discovery** by implementing and testing the scanning process for nearby Bluetooth devices. Evaluated the discovery mechanism to improve device detection and support reliable pairing with the intended Bluetooth earbuds.

---

## 2 July 2026

- Working on implementing **automatic Bluetooth device discovery and pairing** for discoverable Bluetooth earbuds. Investigated scanning mechanisms, RSSI-based device selection, and pairing workflows to enable the ESP32 to automatically detect and connect to available earbuds without requiring manual configuration.
- Testing and refining the auto-pairing process to improve connection reliability and ensure seamless reconnection with the intended Bluetooth earbuds whenever they are available.

---

## 3 July 2026

- Worked on implementing and improving the Bluetooth pairing mechanism between the ESP32 and Bluetooth earbuds.
- Focused on enhancing audio transmission reliability by analyzing the communication pipeline and testing different configurations.

---

## 8 July 2026

- Continued development of Bluetooth pairing and connection management.
- Performed testing to improve connectivity stability and optimize real-time audio transmission between the MEMS microphone and Bluetooth earbuds.

---

## 9 July 2026

- Worked on the mechanical design of the project, refining the enclosure and component layout to improve functionality, assembly, and overall aesthetics.

---

## 10 July 2026

- Further refined the hardware design and prepared the model for fabrication.
- Completed 3D printing of the designed components and evaluated the printed parts for fit, alignment, and usability.

---

## 13 July 2026

- Made design modifications based on testing and assembly observations.
- Continued working on Bluetooth connectivity and audio transmission, focusing on improving connection reliability and overall speech communication performance.

---

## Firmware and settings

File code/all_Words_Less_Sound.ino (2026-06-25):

#include <driver/i2s.h>
#include <math.h>
#include "BluetoothA2DPSource.h"   // ← ADDED

// ─── I2S Pins (unchanged) ─────────────────────────────────
#define I2S_WS   25
#define I2S_SCK  33
#define I2S_SD   32

// ─── Audio Settings ───────────────────────────────────────
// CHANGED: 16000 → 44100 because A2DP requires 44100 Hz
// All filter coefficients below are recalculated for 44100 Hz
#define SAMPLE_RATE  44100
#define BUFFER_SIZE  512
#define NUM_BANDS    4

// ─── Bluetooth A2DP ───────────────────────────────────────
// ADDED: A2DP object and ring buffer
// The ring buffer passes audio between your DSP loop
// and the BT callback which runs on a separate core
BluetoothA2DPSource a2dp_source;

#define RING_SIZE 32768
volatile int16_t ringBuf[RING_SIZE];
volatile int     ringHead = 0;
volatile int     ringTail = 0;

// This function is called automatically by the BT stack
// whenever it needs audio to send to your earphones
// You never call this yourself — the library calls it
int32_t provideAudio(Frame* frame, int32_t frame_count) {
  for (int i = 0; i < frame_count; i++) {
    int16_t sample = 0;
    if (ringHead != ringTail) {
      sample   = ringBuf[ringTail];
      ringTail = (ringTail + 1) % RING_SIZE;
    }
    frame[i].channel1 = sample;   // Left
    frame[i].channel2 = sample;   // Right (same mono audio)
  }
  return frame_count;
}

// ─── DC Offset Removal (unchanged) ───────────────────────
float dcOffset = 0.0f;
const float DC_ALPHA = 0.999f;

float removeDC(float x) {
  dcOffset = DC_ALPHA * dcOffset + (1.0f - DC_ALPHA) * x;
  return x - dcOffset;
}

// ─── High-Pass Filter (~280 Hz cutoff) ────────────────────
// CHANGED: alpha recalculated for 44100 Hz
// RC = 1/(2*pi*280) = 5.684e-4
// dt = 1/44100     = 2.268e-5
// alpha = RC/(RC+dt) = 0.962
float hpf_prev_in  = 0.0f;
float hpf_prev_out = 0.0f;
const float HPF_ALPHA = 0.962f;   // was 0.975 at 16000 Hz

float highPass(float x) {
  float y = HPF_ALPHA * (hpf_prev_out + x - hpf_prev_in);
  hpf_prev_in  = x;
  hpf_prev_out = y;
  return y;
}

// ─── Low-Pass Filter (~3400 Hz cutoff) ────────────────────
// CHANGED: alpha recalculated for 44100 Hz
// RC = 1/(2*pi*3400) = 4.682e-5
// dt = 1/44100       = 2.268e-5
// alpha = dt/(RC+dt) = 0.326
float lpf_prev = 0.0f;
const float LPF_ALPHA = 0.326f;   // was 0.572 at 16000 Hz

float lowPass(float x) {
  lpf_prev += LPF_ALPHA * (x - lpf_prev);
  return lpf_prev;
}

// ─── 4-Band Splitter ──────────────────────────────────────
// CHANGED: all alphas recalculated for 44100 Hz
// formula: alpha = 1 - exp(-2*pi*fc/fs)
// 600  Hz: 1 - exp(-2*pi*600/44100)  = 0.082
// 1200 Hz: 1 - exp(-2*pi*1200/44100) = 0.157
// 2200 Hz: 1 - exp(-2*pi*2200/44100) = 0.269
float bsf_600_prev  = 0.0f;
float bsf_1200_prev = 0.0f;
float bsf_2200_prev = 0.0f;

const float BSF_ALPHA_600  = 0.082f;   // was 0.210 at 16000 Hz
const float BSF_ALPHA_1200 = 0.157f;   // was 0.376 at 16000 Hz
const float BSF_ALPHA_2200 = 0.269f;   // was 0.578 at 16000 Hz

void bandSplit(float x, float bands[4]) {
  bsf_600_prev  += BSF_ALPHA_600  * (x - bsf_600_prev);
  bsf_1200_prev += BSF_ALPHA_1200 * (x - bsf_1200_prev);
  bsf_2200_prev += BSF_ALPHA_2200 * (x - bsf_2200_prev);

  bands[0] = bsf_600_prev;
  bands[1] = bsf_1200_prev - bsf_600_prev;
  bands[2] = bsf_2200_prev - bsf_1200_prev;
  bands[3] = x - bsf_2200_prev;
}

// ─── AGC (unchanged) ──────────────────────────────────────
float agcGain = 1.0f;
const float AGC_MAX     = 8.0f;
const float AGC_MIN     = 0.5f;
const float AGC_ATTACK  = 0.01f;
const float AGC_RELEASE = 0.002f;

float applyAGC(float x, bool active) {
  if (!active) return x;
  float absVal = fabsf(x);
  if (absVal * agcGain > 0.9f)
    agcGain -= AGC_ATTACK * agcGain;
  else
    agcGain += AGC_RELEASE;
  agcGain = fminf(fmaxf(agcGain, AGC_MIN), AGC_MAX);
  float out = x * agcGain;
  return fminf(fmaxf(out, -1.0f), 1.0f);
}

// ─── Noise Estimation ─────────────────────────────────────
double noiseFloor = 0.0;
double noiseBands[NUM_BANDS] = {0.0, 0.0, 0.0, 0.0};

int    calibrationCount = 0;
double calibrationSum   = 0.0;
double calibBandSums[NUM_BANDS] = {0.0, 0.0, 0.0, 0.0};

// CHANGED: 30 → 50 frames
// At 44100 Hz, each 512-sample frame = 11.6 ms
// 50 frames = ~580 ms of calibration (same real-time as before)
const int CALIBRATION_FRAMES = 50;
bool calibrated = false;

// ─── Band Suppression Gains (unchanged) ───────────────────
float bandGains[NUM_BANDS] = {0.02f, 0.02f, 0.02f, 0.02f};

// ─── Temporal Modulation Tracker ──────────────────────────
// CHANGED: 20 → 30 frames
// At 44100 Hz, 30 frames = ~350 ms (same real-time as before)
#define MOD_HISTORY_LEN 30
float rmsHistory[MOD_HISTORY_LEN] = {0};
int   rmsHistIdx  = 0;
bool  rmsHistFull = false;

float computeModulationIndex() {
  int count = rmsHistFull ? MOD_HISTORY_LEN : rmsHistIdx;
  if (count < 6) return 0.0f;

  float mean = 0.0f;
  for (int i = 0; i < count; i++) mean += rmsHistory[i];
  mean /= (float)count;

  if (mean < 1e-10f) return 0.0f;

  float var = 0.0f;
  for (int i = 0; i < count; i++) {
    float d = rmsHistory[i] - mean;
    var += d * d;
  }
  return sqrtf(var / (float)count) / mean;
}

// ─── VAD State (unchanged) ────────────────────────────────
int  confirmCount  = 0;
int  holdoverCount = 0;
bool speechActive  = false;

// ─── Filtered Sample Buffer (unchanged) ───────────────────
static float filteredBuf[BUFFER_SIZE];

void setup() {
  Serial.begin(115200);

  // ─── I2S Microphone (unchanged except sample rate) ────
  i2s_config_t i2s_config = {
    .mode                 = (i2s_mode_t)(I2S_MODE_MASTER | I2S_MODE_RX),
    .sample_rate          = SAMPLE_RATE,
    .bits_per_sample      = I2S_BITS_PER_SAMPLE_32BIT,
    .channel_format       = I2S_CHANNEL_FMT_ONLY_LEFT,
    .communication_format = I2S_COMM_FORMAT_STAND_I2S,
    .intr_alloc_flags     = ESP_INTR_FLAG_LEVEL1,
    .dma_buf_count        = 4,
    .dma_buf_len          = BUFFER_SIZE,
    .use_apll             = false
  };

  i2s_pin_config_t pin_config = {
    .bck_io_num   = I2S_SCK,
    .ws_io_num    = I2S_WS,
    .data_out_num = I2S_PIN_NO_CHANGE,
    .data_in_num  = I2S_SD
  };

  i2s_driver_install(I2S_NUM_0, &i2s_config, 0, NULL);
  i2s_set_pin(I2S_NUM_0, &pin_config);

  // ─── ADDED: Start Bluetooth A2DP ──────────────────────
  // Replace the text below with your earphone's exact BT name
  // Find this name by scanning for BT devices on your phone
  // Example: "boAt Airdopes 141" or "WI-C100" or "JBL GO 3"
  // Capitalization must match exactly
  a2dp_source.start("Bose QuietComfort Earbuds", provideAudio);

  Serial.println("BT connecting — put earphones in pairing mode now");
  Serial.println("Calibrating — stay quiet for ~1 second...");
}

void loop() {
  int32_t inBuffer[BUFFER_SIZE];
  size_t  bytesRead = 0;

  i2s_read(I2S_NUM_0,
           inBuffer,
           sizeof(inBuffer),
           &bytesRead,
           portMAX_DELAY);

  int samples = bytesRead / sizeof(int32_t);

  double sumSquares = 0.0;
  double bandEnergy[NUM_BANDS] = {0.0, 0.0, 0.0, 0.0};

  float saved_bsf_600  = bsf_600_prev;
  float saved_bsf_1200 = bsf_1200_prev;
  float saved_bsf_2200 = bsf_2200_prev;

  // ═══════════════════════════════════════════════════════
  //  PASS 1 — Filter and compute metrics (unchanged)
  // ═══════════════════════════════════════════════════════

  for (int i = 0; i < samples; i++) {
    int32_t raw = inBuffer[i] >> 8;
    float x = (float)raw / 8388608.0f;

    x = removeDC(x);
    x = highPass(x);
    x = lowPass(x);

    filteredBuf[i] = x;

    float bands[4];
    bandSplit(x, bands);
    for (int b = 0; b < NUM_BANDS; b++) {
      bandEnergy[b] += (double)bands[b] * (double)bands[b];
    }
    sumSquares += (double)x * (double)x;
  }

  double rms = sqrt(sumSquares / samples);

  double bandRms[NUM_BANDS];
  for (int b = 0; b < NUM_BANDS; b++) {
    bandRms[b] = sqrt(bandEnergy[b] / samples);
  }

  // ═══════════════════════════════════════════════════════
  //  CALIBRATION (unchanged)
  // ═══════════════════════════════════════════════════════

  if (!calibrated) {
    calibrationSum += rms;
    for (int b = 0; b < NUM_BANDS; b++) {
      calibBandSums[b] += bandRms[b];
    }
    calibrationCount++;

    if (calibrationCount >= CALIBRATION_FRAMES) {
      noiseFloor = calibrationSum / calibrationCount;
      for (int b = 0; b < NUM_BANDS; b++) {
        noiseBands[b] = calibBandSums[b] / calibrationCount;
      }
      calibrated = true;
      Serial.println("--- Calibration Complete. Listening... ---");
    } else {
      Serial.print("Calibrating... ");
      Serial.print(calibrationCount);
      Serial.print(" / ");
      Serial.println(CALIBRATION_FRAMES);
    }
    return;
  }

  // ═══════════════════════════════════════════════════════
  //  FEATURE COMPUTATION (unchanged)
  // ═══════════════════════════════════════════════════════

  const float eps = 1e-10f;

  float logSum = 0.0f;
  float linSum = 0.0f;
  for (int b = 0; b < NUM_BANDS; b++) {
    logSum += logf((float)bandRms[b] + eps);
    linSum += (float)bandRms[b];
  }
  float geoMean          = expf(logSum / NUM_BANDS);
  float ariMean          = linSum / NUM_BANDS;
  float spectralFlatness = geoMean / (ariMean + eps);

  float midEnergy  = (float)(bandRms[1] + bandRms[2]);
  float edgeEnergy = (float)(bandRms[0] + bandRms[3]);
  float bandRatio  = midEnergy / (edgeEnergy + eps);

  rmsHistory[rmsHistIdx] = (float)rms;
  rmsHistIdx = (rmsHistIdx + 1) % MOD_HISTORY_LEN;
  if (rmsHistIdx == 0) rmsHistFull = true;
  float modulationIdx = computeModulationIndex();

  // ═══════════════════════════════════════════════════════
  //  VAD DECISION (unchanged)
  // ═══════════════════════════════════════════════════════

  bool energyOK    = (rms > noiseFloor * 3.0);
  bool modulationOK = (modulationIdx > 0.20f);
  bool flatnessOK  = (spectralFlatness < 0.70f);
  bool bandRatioOK = (bandRatio > 0.8f);

  bool rawVAD = energyOK && modulationOK && (flatnessOK || bandRatioOK);

  if (rawVAD) {
    confirmCount++;
    holdoverCount = 20;   // CHANGED: 12 → 20 frames (~232 ms at 44100 Hz)
    if (confirmCount >= 2) speechActive = true;
  } else {
    confirmCount = 0;
    if (holdoverCount > 0) holdoverCount--;
    else speechActive = false;
  }

  // ═══════════════════════════════════════════════════════
  //  NOISE FLOOR UPDATE (unchanged)
  // ═══════════════════════════════════════════════════════

  if (!speechActive) {
    for (int b = 0; b < NUM_BANDS; b++) {
      noiseBands[b] = 0.95 * noiseBands[b] + 0.05 * bandRms[b];
    }
    if (rms < noiseFloor * 2.0)
      noiseFloor = 0.98 * noiseFloor + 0.02 * rms;
  }
  if (rms < noiseFloor * 1.5)
    noiseFloor = 0.9995 * noiseFloor + 0.0005 * rms;

  // ═══════════════════════════════════════════════════════
  //  NOISE SUPPRESSION GAINS (unchanged)
  // ═══════════════════════════════════════════════════════

  for (int b = 0; b < NUM_BANDS; b++) {
    float newGain;
    if (bandRms[b] > eps) {
      float snr  = (float)(bandRms[b] / (noiseBands[b] + eps));
      newGain    = snr / (snr+1.0f);
      float flr  = speechActive ? 0.08f : 0.02f;
      newGain    = fmaxf(newGain, flr);
    } else {
      newGain = 0.02f;
    }
    bandGains[b] = 0.7f * bandGains[b] + 0.3f * newGain;
  }
    Serial.print("Gains: ");
    for (int b = 0; b < NUM_BANDS; b++) {
    Serial.print(bandGains[b], 2);
    Serial.print(" ");
}
Serial.println();

  // ═══════════════════════════════════════════════════════
  //  PASS 2 — Noise suppression + AGC (unchanged)
  // ═══════════════════════════════════════════════════════

  bsf_600_prev  = saved_bsf_600;
  bsf_1200_prev = saved_bsf_1200;
  bsf_2200_prev = saved_bsf_2200;

  for (int i = 0; i < samples; i++) {
    float x = filteredBuf[i];

    float bands[4];
    bandSplit(x, bands);

    float output = 0.0f;
    for (int b = 0; b < NUM_BANDS; b++) output += bands[b] * bandGains[b];

    output *= 4.0f;
    if (!speechActive) output *= 0.10f;
    output = fminf(fmaxf(output, -1.0f), 1.0f);

    inBuffer[i] = (int32_t)(output * 8388608.0f);
  }

  // ═══════════════════════════════════════════════════════
  //  ADDED: Push processed audio into ring buffer for BT
  // Converts 24-bit samples → 16-bit and writes to ring buffer
  // The provideAudio callback above drains this buffer
  // ═══════════════════════════════════════════════════════

  for (int i = 0; i < samples; i++) {
    int16_t s    = (int16_t)(inBuffer[i] >> 8);
    int     next = (ringHead + 1) % RING_SIZE;
    if (next != ringTail) {
      ringBuf[ringHead] = s;
      ringHead = next;
    }
  }

  // ═══════════════════════════════════════════════════════
  //  SERIAL MONITOR (unchanged)
  // ═══════════════════════════════════════════════════════

  // Serial.print("RMS:");
  // Serial.print(rms, 6);
  // Serial.print("AGC = ");
  // Serial.println(agcGain);
  // Serial.print("  Floor:");
  // Serial.print(noiseFloor, 6);
  // Serial.print("  Flat:");
  // Serial.print(spectralFlatness, 2);
  // Serial.print("  BR:");
  // Serial.print(bandRatio, 2);
  // Serial.print("  Mod:");
  // Serial.print(modulationIdx, 2);
  // Serial.print("  |E:");
  // Serial.print(energyOK     ? "Y" : "N");
  // Serial.print(" M:");
  // Serial.print(modulationOK ? "Y" : "N");
  // Serial.print(" F:");
  // Serial.print(flatnessOK   ? "Y" : "N");
  // Serial.print(" B:");
  // Serial.print(bandRatioOK  ? "Y" : "N");
  // Serial.print("|  >> ");
  // Serial.println(speechActive ? "SPEECH" : "NOISE");


}

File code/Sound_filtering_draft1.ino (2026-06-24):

#include <driver/i2s.h>
#include <math.h>

// ─── I2S Pins ────────────────────────────────────────────
#define I2S_WS   25
#define I2S_SCK  33
#define I2S_SD   32

// ─── Settings ────────────────────────────────────────────
#define SAMPLE_RATE  16000
#define BUFFER_SIZE  256

// ─── DC Offset Removal ───────────────────────────────────
// Tracks and removes the slow-moving DC bias of the mic
float dcOffset = 0.0f;
const float DC_ALPHA = 0.999f;  // Very slow tracking — only removes true DC

float removeDC(float x) {
  dcOffset = DC_ALPHA * dcOffset + (1.0f - DC_ALPHA) * x;
  return x - dcOffset;
}

// ─── High-Pass Filter (~150 Hz cutoff) ───────────────────
// Removes engine rumble, road vibration, wind drone
float hpf_prev_in  = 0.0f;
float hpf_prev_out = 0.0f;
const float HPF_ALPHA = 0.988f;

float highPass(float x) {
  float y = HPF_ALPHA * (hpf_prev_out + x - hpf_prev_in);
  hpf_prev_in  = x;
  hpf_prev_out = y;
  return y;
}

// ─── Low-Pass Filter (~3400 Hz cutoff) ───────────────────
// Removes high-frequency hiss and electrical interference
float lpf_prev = 0.0f;
const float LPF_ALPHA = 0.572f;

float lowPass(float x) {
  lpf_prev = lpf_prev + LPF_ALPHA * (x - lpf_prev);
  return lpf_prev;
}

// ─── Adaptive Noise Floor ────────────────────────────────
// Starts with a calibration period instead of a cold single-buffer init
double noiseFloor       = 0.0;
int    calibrationCount = 0;
double calibrationSum   = 0.0;
const int CALIBRATION_BUFFERS = 20;   // ~1.3 seconds of silence at startup
bool calibrated = false;

// ─── VAD Holdover ────────────────────────────────────────
// Keeps speech flag alive for N buffers after signal drops
// Prevents choppy cuts between words
int holdoverCount = 0;
const int HOLDOVER_BUFFERS = 8;   // ~0.5 seconds of holdover

// ─── AGC State ───────────────────────────────────────────
// Tracks the recent peak and applies a gain to normalize output level
float agcGain        = 1.0f;
const float AGC_MAX  = 8.0f;    // Maximum gain (avoid over-amplifying silence)
const float AGC_MIN  = 0.5f;    // Minimum gain (avoid crushing loud input)
const float AGC_ATTACK  = 0.01f;  // How fast gain reduces when signal is loud
const float AGC_RELEASE = 0.001f; // How slowly gain recovers when signal is quiet

float applyAGC(float x) {
  float absVal = fabsf(x);

  // If signal level is high, reduce gain quickly (attack)
  // If signal level is low, recover gain slowly (release)
  if (absVal * agcGain > 0.9f) {
    agcGain -= AGC_ATTACK * agcGain;
  } else {
    agcGain += AGC_RELEASE;
  }

  // Clamp gain within safe range
  if (agcGain > AGC_MAX) agcGain = AGC_MAX;
  if (agcGain < AGC_MIN) agcGain = AGC_MIN;

  // Apply gain and hard-clip to prevent overflow
  float out = x * agcGain;
  if (out >  1.0f) out =  1.0f;
  if (out < -1.0f) out = -1.0f;
  return out;
}

void setup() {
  Serial.begin(115200);

  i2s_config_t i2s_config = {
    .mode                 = (i2s_mode_t)(I2S_MODE_MASTER | I2S_MODE_RX),
    .sample_rate          = SAMPLE_RATE,
    .bits_per_sample      = I2S_BITS_PER_SAMPLE_32BIT,
    .channel_format       = I2S_CHANNEL_FMT_ONLY_LEFT,
    .communication_format = I2S_COMM_FORMAT_STAND_I2S,
    .intr_alloc_flags     = ESP_INTR_FLAG_LEVEL1,
    .dma_buf_count        = 4,
    .dma_buf_len          = BUFFER_SIZE,
    .use_apll             = false
  };

  i2s_pin_config_t pin_config = {
    .bck_io_num   = I2S_SCK,
    .ws_io_num    = I2S_WS,
    .data_out_num = I2S_PIN_NO_CHANGE,
    .data_in_num  = I2S_SD
  };

  i2s_driver_install(I2S_NUM_0, &i2s_config, 0, NULL);
  i2s_set_pin(I2S_NUM_0, &pin_config);

  Serial.println("Calibrating noise floor — stay quiet...");
}

void loop() {
  int32_t buffer[BUFFER_SIZE];
  size_t bytesRead = 0;

  i2s_read(I2S_NUM_0,
           buffer,
           sizeof(buffer),
           &bytesRead,
           portMAX_DELAY);

  int samples = bytesRead / sizeof(int32_t);
  double sumSquares = 0.0;

  for (int i = 0; i < samples; i++) {

    // Step 1: Extract 24-bit sample from 32-bit I2S frame
    int32_t raw = buffer[i] >> 8;

    // Step 2: Normalize to float -1.0 to +1.0
    float x = (float)raw / 8388608.0f;

    // Step 3: Remove DC offset
    x = removeDC(x);

    // Step 4: High-pass filter (removes rumble below ~150 Hz)
    x = highPass(x);

    // Step 5: Low-pass filter (removes hiss above ~3400 Hz)
    // Steps 4+5 together = band-pass keeping voice frequencies only
    x = lowPass(x);

    // Step 6: AGC — normalize output level
    x = applyAGC(x);

    // Accumulate RMS
    sumSquares += (double)x * (double)x;

    // Write processed sample back to buffer
    buffer[i] = (int32_t)(x * 8388608.0f);
  }

  // ─── RMS of this buffer ──────────────────────────────
  double rms = sqrt(sumSquares / samples);

  // ─── Calibration Phase ───────────────────────────────
  // Collect several quiet buffers at startup before trusting the noise floor
  if (!calibrated) {
    calibrationSum += rms;
    calibrationCount++;

    if (calibrationCount >= CALIBRATION_BUFFERS) {
      noiseFloor = calibrationSum / calibrationCount;
      calibrated = true;
      Serial.print("Noise floor calibrated: ");
      Serial.println((long)noiseFloor);
    } else {
      Serial.print("Calibrating... buffer ");
      Serial.print(calibrationCount);
      Serial.print(" / ");
      Serial.println(CALIBRATION_BUFFERS);
    }
    return;  // Don't transmit during calibration
  }

  // ─── Adaptive Noise Floor Update ─────────────────────
  // Only update floor when signal is close to background level
  // Tighter condition (1.2×) prevents loud noise from raising the floor
  if (rms < noiseFloor * 1.2) {
    noiseFloor = 0.995 * noiseFloor + 0.005 * rms;
  }

  // ─── Voice Activity Detection (VAD) ──────────────────
  bool speechDetected = (rms > noiseFloor * 3.0);

  // Holdover: keep speech flag alive for a few buffers after signal drops
  // Prevents choppy cuts between words during natural pauses
  if (speechDetected) {
    holdoverCount = HOLDOVER_BUFFERS;
  } else if (holdoverCount > 0) {
    holdoverCount--;
    speechDetected = true;  // Keep flag alive during holdover
  }

  // ─── Output ──────────────────────────────────────────
  // If no speech detected, zero out the buffer (mute)
  // This is where you will later pass buffer[] to A2DP transmitter
  if (!speechDetected) {
    memset(buffer, 0, samples * sizeof(int32_t));
  }

  // ─── Serial Monitor ──────────────────────────────────
  Serial.print("RMS: ");
  Serial.print((long)rms);
  Serial.print("  Floor: ");
  Serial.print((long)noiseFloor);
  Serial.print("  Ratio: ");
  Serial.print(rms / (noiseFloor + 1.0), 2);
  Serial.print("  Gain: ");
  Serial.print(agcGain, 2);
  Serial.print("  Status: ");
  Serial.println(speechDetected ? "SPEECH" : "NOISE");
}

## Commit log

2026-06-05 Document June 2026 activities in polar bear file
    Added detailed entries for June 2026 activities related to 3D modeling and laser cutting.
2026-06-05 Update panda
    added path of the file of our CAD project ( 3d bottle )
2026-06-05 Add files via upload
    Ankita's 3D modelled water bottle
    [Ankita Water Bottle.f3z]
2026-06-05 Add files via upload
    Useless product - 'SQUARE WHEEL'
2026-06-05 Fix image paths in polar bear training material
    Added ID image
2026-06-05 Update photo reference in polar bear document
    image of 3D printed Wheel
2026-06-05 Add files via upload
    Useless product - Square wheel stl file
    [Square_wheel.stl]
2026-06-05 Add files via upload
    Added Riya's 3d bottle .stl file
    [Riya-3D Bottle.stl]
2026-06-05 Add files via upload
    Square wheel image
2026-06-05 Add files via upload
    Uploaded laser cut makermania ID
2026-06-06 Update Video of Useless Product.md
    Uploaded the demonstration video of our Square Wheel project on YouTube and pasting its link here .
2026-06-10 Add files via upload
    Scamper activity - Find my device
2026-06-18 Fix diagram flow in README.md
2026-06-24 Create Filtered.ino
    uploaded the working code which does sound filtering and detect human speech and also differentiates noise and speech
    [Filtered.ino]
2026-06-29 Create Bluetooth_Classic _GAP_API.ino
    Bluetooth Classic GAP API code to enable scanning of near by devices with their mac address and rssi index
2026-06-29 Update output table in README
    Remove 'Wireless Audio Signal' from the output table.
2026-07-01 Update daily worklog with recent findings and tasks
    Documented findings on voice amplification and noise cancellation challenges. Added details on Bluetooth device scanning and discovery improvements.
2026-07-02 Document work on Bluetooth auto-discovery and pairing
    Added new section for work on automatic Bluetooth device discovery and pairing, detailing investigations and testing for improved connection reliability.
2026-07-12 The 3d printed enclosure was uploaded
    [Prototype1 - RideConnect.3mf, Prototype2 - RideConnect.3mf]
2026-07-12 Edit file
    [Prototype1 - RideConnect.3mf]
2026-07-12 Prototype Cad files
    [Prototype1 - RideConnect.stl, Prototype2 - RideConnect.stl]
2026-07-13 Update daily worklog with recent project activities
    Added detailed work logs for Bluetooth device discovery, pairing, and hardware design improvements.
2026-07-13 Clarify Bluetooth audio streaming details in README
    Updated the description of the audio processing and Bluetooth streaming components to clarify the use of the ESP32's built-in Bluetooth module instead of the RS2597 module.
2026-07-13 Add files via upload
    prototype version
2026-07-13 Revise prototype descriptions and testing criteria
    Updated descriptions and lessons learned for prototypes and testing plan in README.md.
2026-07-13 Update README with Arduino IDE purpose
2026-07-13 Update README with RideConnect STL link
    Add link to RideConnect STL file in CAD section.
2026-07-22 Create Clutched
    The final implementation files for the Bluetooth communication system and the refined DSP pipeline have been uploaded. Additionally, the "No Device Found" issue has been successfully addressed by introducing an automatic rescan feature that performs a Bluetooth scan every 2 seconds until a compatible earbud is detected and a connection is established.
2026-07-22 Create tmp.txt
    2nd attempt in making a separate file :
    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
